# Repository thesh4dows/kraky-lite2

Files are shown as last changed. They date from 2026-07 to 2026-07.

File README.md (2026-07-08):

# kraky-lite2

Kraky-lite2 is the second version of the project kraky-lite.
The project Kraky-lite was inspired by Kraky, another project that i'm developing, and the focus
is to create a cheaper and DIY alternative for the flipper zero.

In this version the PCB is divided in 2 layers, one for power delivery and one for signal.

You can use it connected to a battery via the 18650 slot in the back or connected via usb-c.

I would soggest putting first all the smd commponents on the top layer, then the smd components on the bottom layer, and last the tht components.

I started this journey because i want to create a better version of my project kraky-lite, and i'm doing it by first using smd components instead of the 
tht modules so i can do some expirience soldering very small parts and stopping using pre made modules but recreating them myself.

---

# Main Components
| Function | Component |
|---|---|
| Logic board | **ESP32-S3 N16R8** |
| wifi | **nrf24l01** |
| Sub-GHz | **CC1101** |
| Battery charger | **CN3163** |
| Battery | **INR18650** |
| microSD Slot | **MSD4A** |
| Buttons | 1 tactile buttons and a rotary encoder |
| Display | TFT Display |
| COM converter | **CH343P** |

---

# WIRING DIAGRAM

# ESP32



 # POWER DELIVERY SYSTEM
 


# WIFI



# SUB-GHZ



# MICROSD SLOT



# DISPLAY



---

# PCB



---

# 3D render



---

# Responsible Use
Kraky-lite2 is built to make it easier for anyone to explore and understand how multifunction electronic devices work in everyday life. It’s not intended for bypassing security systems or breaking any laws.

All features are implemented with an educational and experimental focus.

---

# Tools Used

- KiCad 10
- Fusion360
- PlatformIO
---
## Contributing

All the Kraky's tools are an **open and educational project**.  
Feedback, suggestions, and improvements are always welcome.

---

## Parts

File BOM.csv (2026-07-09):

name | value | link | description | cost | quantity
resistors
R1 | 56k | https://it.aliexpress.com/item/1005010070793079.html?curPageLogUid=H7QIyXNC0fT4 | 805 | 4.37 | 1
R2 | 5.1k | https://it.aliexpress.com/item/1005010070793079.html?curPageLogUid=H7QIyXNC0fT4 | 805 | 4.37 | 2
R3 | 330 | https://it.aliexpress.com/item/1005010070793079.html?curPageLogUid=H7QIyXNC0fT4 | 805 | 4.37 | 1
R4 | 3.6k | https://it.aliexpress.com/item/1005010070793079.html?curPageLogUid=H7QIyXNC0fT4 | 805 | 4.37 | 1
R5 | 100 | https://it.aliexpress.com/item/1005010070793079.html?curPageLogUid=H7QIyXNC0fT4 | 805 | 4.33 | 1
R6 | R2 | R2 | R2 | R2 | R2
R7 | 1M | https://it.aliexpress.com/item/1005010070793079.html?curPageLogUid=H7QIyXNC0fT4 | 805 | 4.38 | 1
R8 | 22k | https://it.aliexpress.com/item/1005010070793079.html?curPageLogUid=H7QIyXNC0fT4 | 805 | 4.37 | 1
R9 | 10k | https://it.aliexpress.com/item/1005010070793079.html?curPageLogUid=H7QIyXNC0fT4 | 805 | 4.41 | 3
R10 | R9 | R9 | R9 | R9 | R9
R11 | R9 | R9 | R9 | R9 | R9
capacitors
C1 | 27 pF | https://it.aliexpress.com/item/1005005929029743.html?curPageLogUid=6vnH26Bvr1Cc | 805 | 4.48 | 2
C2 | C1 | C1 | C1 | C1 | C1
C3 | 100 nF | https://it.aliexpress.com/item/1005005929029743.html?curPageLogUid=6vnH26Bvr1Cc | 805 | 4.30 | 10
C4 | C3 | C3 | C3 | C3 | C3
C5 | C3 | C3 | C3 | C3 | C3
C6 | C3 | C3 | C3 | C3 | C3
C7 | C3 | C3 | C3 | C3 | C3
C8 | C3 | C3 | C3 | C3 | C3
C9 | C3 | C3 | C3 | C3 | C3
C10 | 220 pF | https://it.aliexpress.com/item/1005005929029743.html?curPageLogUid=6vnH26Bvr1Cc | 805 | 4.48 | 2
C11 | 3.9 pF | https://it.aliexpress.com/item/1005005929029743.html?curPageLogUid=6vnH26Bvr1Cc | 805 | 4.48 | 2
C12 | 8.2 pF | https://it.aliexpress.com/item/1005005929029743.html?curPageLogUid=6vnH26Bvr1Cc | 805 | 4.48 | 1
C13 | C10 | C10 | C10 | C10 | C10
C14 | C11 | C11 | C11 | C11 | C11
C15 | 5.6 pF | https://it.aliexpress.com/item/1005005929029743.html?curPageLogUid=6vnH26Bvr1Cc | 805 | 4.48 | 1
C16 | 0.1 uF | https://it.aliexpress.com/item/1005005929029743.html?curPageLogUid=6vnH26Bvr1Cc | 805 | 4.30 | 2
C17 | C16 | C16 | C16 | C16 | C16
C18 | 22 uF | https://it.aliexpress.com/item/1005005929029743.html?curPageLogUid=6vnH26Bvr1Cc | 805 | 4.71 | 1
C19 | 4.7 uF | https://it.aliexpress.com/item/1005005929029743.html?curPageLogUid=6vnH26Bvr1Cc | 805 | 4.71 | 1
C20 | C3 | C3 | C3 | C3 | C3
C21 | 22 pF | https://it.aliexpress.com/item/1005005929029743.html?curPageLogUid=6vnH26Bvr1Cc | 805 | 4.48 | 2
C22 | C21 | C21 | C21 | C21 | C21
C23 | 10 nF | https://it.aliexpress.com/item/1005005929029743.html?curPageLogUid=6vnH26Bvr1Cc | 805 | 4.45 | 2
C24 | 1 nF | https://it.aliexpress.com/item/1005005929029743.html?curPageLogUid=6vnH26Bvr1Cc | 805 | 4.45 | 2
C25 | 2.2 nF | https://it.aliexpress.com/item/1005005929029743.html?curPageLogUid=6vnH26Bvr1Cc | 805 | 4.45 | 1
C26 | 4.7 pF | https://it.aliexpress.com/item/1005005929029743.html?curPageLogUid=6vnH26Bvr1Cc | 805 | 4.45 | 1
C27 | 1.5 pF | https://it.aliexpress.com/item/1005005929029743.html?curPageLogUid=6vnH26Bvr1Cc | 805 | 4.45 | 1
C28 | 1 pF | https://it.aliexpress.com/item/1005005929029743.html?curPageLogUid=6vnH26Bvr1Cc | 805 | 4.45 | 1
C29 | C3 | C3 | C3 | C3 | C3
C30 | C3 | C3 | C3 | C3 | C3
C31 | 10 uF | https://it.aliexpress.com/item/1005005929029743.html?curPageLogUid=6vnH26Bvr1Cc | 805 | 4.56 | 2
C32 | C31 | C31 | C31 | C31 | C31
C33 | C23 | C23 | C23 | C23 | C23
C34 | C24 | C24 | C24 | C24 | C24
C35 | 220 uF | https://it.aliexpress.com/item/1005007283100591.html?curPageLogUid=XSGI4u0Avtv0 | 1210 | 6.09 | 2
C36 | C35 | C35 | C35 | C35 | C35
inductors
L1 | 27 nH | https://it.aliexpress.com/item/1005003062755166.html?curPageLogUid=HGVAlLHM7vi2 | 805 | 4.66 | 3
L2 | L1 | L1 | L1 | L1 | L1
L3 | 22 nH | https://it.aliexpress.com/item/1005003062755166.html?curPageLogUid=HGVAlLHM7vi2 | 805 | 4.66 | 1
L4 | L1 | L1 | L1 | L1 | L1
L5 | 2.7 nH | https://it.aliexpress.com/item/1005003062755166.html?curPageLogUid=HGVAlLHM7vi2 | 805 | 4.69 | 1
L6 | 8.2 nH | https://it.aliexpress.com/item/1005003062755166.html?curPageLogUid=HGVAlLHM7vi2 | 805 | 4.66 | 1
L7 | 3.9 nH | https://it.aliexpress.com/item/1005003062755166.html?curPageLogUid=HGVAlLHM7vi2 | 805 | 4.66 | 1
diodes
D1 | 1N5817 | https://it.aliexpress.com/item/1005006884142108.html?curPageLogUid=pNE6jaPw82sV |  | 5.99 | 3
D2 | LED | https://it.aliexpress.com/item/32868897187.html?curPageLogUid=WrrkifD2CvJr | 1206 | 4.63 | 1
D3 | LED | https://it.aliexpress.com/item/32868897187.html?curPageLogUid=WrrkifD2CvJr | 1206 | 4.63 | 1
D4 | LED | https://it.aliexpress.com/item/32868897187.html?curPageLogUid=WrrkifD2CvJr | 1206 | 4.63 | 1
D5 | D1 | D1 | D1 | D1 | D1
D6 | D1 | D1 | D1 | D1 | D1
Crystals
Y1 | 26 MHz | https://it.aliexpress.com/item/1005004711354176.html?curPageLogUid=sEWfQk2pigRD | 5032 | 5.79 | 1
Y2 | 16MHz | https://it.aliexpress.com/item/1005007210644647.html?curPageLogUid=bcvfZR4XvBPS | 5032 | 7.15 | 1
switches
SW1 | rotary encoder | https://it.aliexpress.com/item/1005005983134515.html?curPageLogUid=CHuD8wUJHaKP |  | 6.19 | 1
SW2 | RST | https://it.aliexpress.com/item/1005008404608815.html?curPageLogUid=beYw408Avuco | 3x6 | 5.36 | 2
SW3 | BOOT | SW2 | SW2 | SW2 | SW2
SW4 | BACK | https://it.aliexpress.com/item/1005006870284823.html?curPageLogUid=iBAjoDabdN8o | 6x6 | 6.01 | 1
SW5 | ON/OFF | https://it.aliexpress.com/item/1005004328667818.html?scm_id=1007.40050.354490.0&scm-url=1007.40050.354490.0 | tht | 5.68 | 1
connectors
J1 | usb-c port | https://it.aliexpress.com/item/1005010643898257.html?curPageLogUid=aFt3XDvcOZhM |  | 5.36 | 1
J2 | display | https://it.aliexpress.com/item/1005007561214068.html?curPageLogUid=LR6KpiatdhUQ |  | 9.69 | 1
J3 | battery holder | https://it.aliexpress.com/item/4000692031094.html?curPageLogUid=Iut4p1SU8Gy9 |  | 5.04 | 1
J4 | 142-0701-501 | https://it.aliexpress.com/item/1005009514982478.html?curPageLogUid=lCuaA8hYuMzd | sma antenna | 5.62 | 2
J5 | MSD-4-A | https://it.aliexpress.com/item/1005006273533788.html?scm_id=1007.40050.354490.0&scm-url=1007.40050.354490.0 | microsd-slot | 5.25 | 1
J6 | J4 | J4 | J4 | J4 | J4
ics
U1 | AMS1117-3.3 | https://it.aliexpress.com/item/1005007027620474.html?curPageLogUid=eo6dvrBMm3cE |  | 4.93 | 1
U2 | AP2112K-3.3TRG1 | https://it.aliexpress.com/item/1005005807114594.html?curPageLogUid=mb5UjEPLbEDJ |  | 5.06 | 1
U3 | CH343P | https://it.aliexpress.com/item/1005009691777003.html?curPageLogUid=lfFt8St0bZKK |  | 7.54 | 1
U4 | CN3063-SOIC8 | https://it.aliexpress.com/item/1005006908180461.html?curPageLogUid=8cHjriHsLvvB |  | 5.59 | 1
U5 | NRF24L01 | https://it.aliexpress.com/item/1005008669394507.html?curPageLogUid=WSLfC61CjqIJ |  | 6.25 | 1
U6 | CC1101 | https://it.aliexpress.com/item/1005007128993296.html?curPageLogUid=uCi7b2Ehsp0B |  | 4.89 | 1
U7 | ESP32-S3-WROOM-1 | https://it.aliexpress.com/item/1005006214506085.html |  | 7.98 | 1
others
battery |  | https://it.aliexpress.com/item/4000809394148.html?curPageLogUid=ac2SQacPb3IK |  | 4.39 | 1
antennas |  | https://it.aliexpress.com/item/1005009456185238.html?curPageLogUid=LOvsTqpqLuYX |  | 6.10 | 2
tools
solder paste |  | https://it.aliexpress.com/item/1005008590694612.html?curPageLogUid=S2Oe7UAJmCP7 |  | 6.32 | 1
solder spool |  | https://it.aliexpress.com/item/1005012037824511.html?curPageLogUid=fqKpRQII2cfI |  | 13.59 | 1
PCB
pcb |  | jlcpcb |  | 30.21 | 1
stencil |  | pcb |  | pcb | 1

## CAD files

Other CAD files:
3D renders/kraky-lite2.3mf

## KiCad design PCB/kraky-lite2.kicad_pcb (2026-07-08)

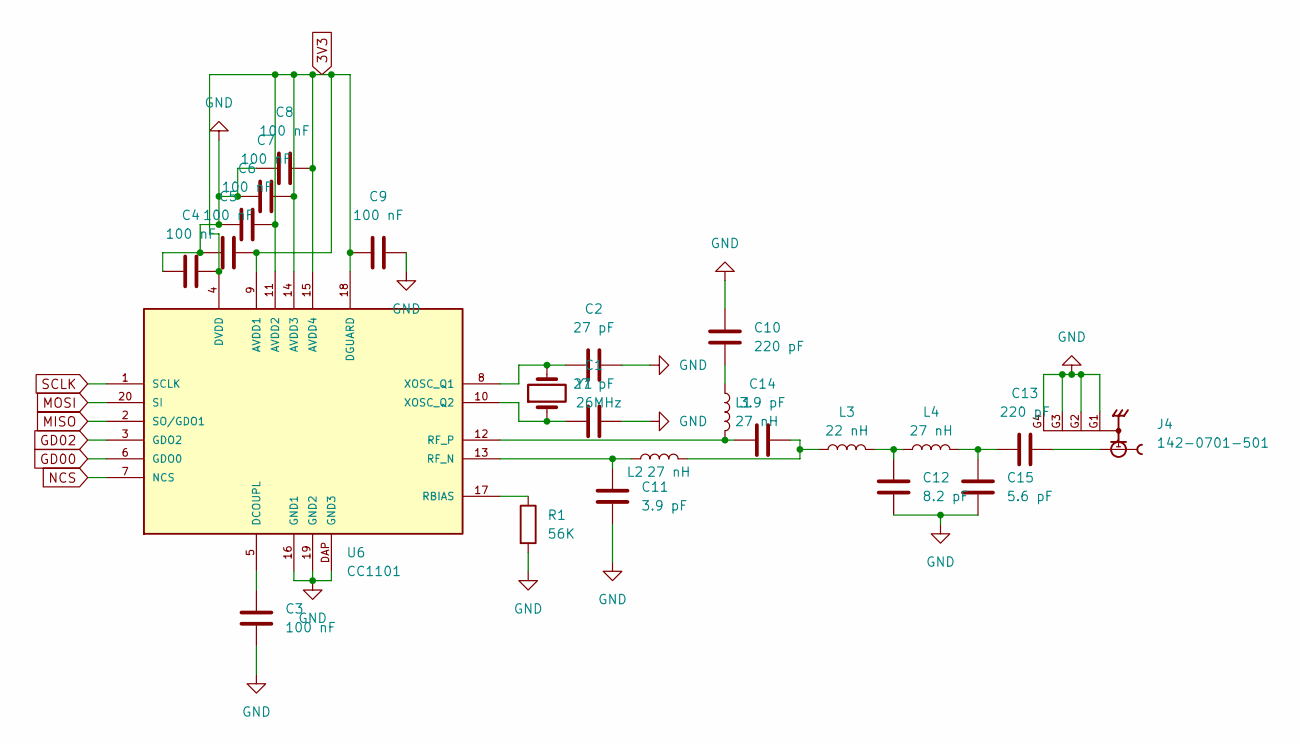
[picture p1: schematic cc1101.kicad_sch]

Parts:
C1, C2: 27 pF; C_0805_2012Metric
C3, C4, C5, C6, C7, C8, C9: 100 nF; C_0805_2012Metric
C10, C13: 220 pF; C_0805_2012Metric
C11, C14: 3.9 pF; C_0805_2012Metric
C12: 8.2 pF; C_0805_2012Metric
C15: 5.6 pF; C_0805_2012Metric
J4: 142-0701-501; SMA_Molex_73251-1153_EdgeMount_Horizontal; PARTREV 7c
L1, L2, L4: 27 nH; L_0805_2012Metric
L3: 22 nH; L_0805_2012Metric
R1: 56K; R_0805_2012Metric
U6: CC1101; QLP20
Y1: 26MHz; Crystal_SMD_5032-2Pin_5.0x3.2mm_HandSoldering

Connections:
3V3: C4.2, C5.2, C6.2, C7.2, C8.2, C9.2, U6.4 (DVDD), U6.9 (AVDD1), U6.11 (AVDD2), U6.14 (AVDD3), U6.15 (AVDD4), U6.18 (DGUARD); also elsewhere on the board
GD00: U6.6 (GDO0); also elsewhere on the board
GD02: U6.3 (GDO2); also elsewhere on the board
GND: C1.2, C2.2, C3.2, C4.1, C5.1, C6.1, C7.1, C8.1, C9.1, C10.2, C11.1, C12.2, C15.2, J4.G1, J4.G2, J4.G3, J4.G4, R1.2, U6.16 (GND1), U6.19 (GND2), U6.DAP (GND3); also elsewhere on the board
MISO: U6.2 (SO/GDO1); also elsewhere on the board
MOSI: U6.20 (SI); also elsewhere on the board
NCS: U6.7 (NCS); also elsewhere on the board
unnamed: C10.1, L1.1
unnamed: C12.1, L3.2, L4.1
unnamed: C13.1, C15.1, L4.2
unnamed: C13.2, J4.1
unnamed: C14.2, L2.2, L3.1
unnamed: C3.1, U6.5 (DCOUPL)
unnamed: R1.1, U6.17 (RBIAS)
unnamed: C11.2, L2.1, U6.13 (RF_N)
unnamed: C14.1, L1.2, U6.12 (RF_P)
unnamed: C2.1, U6.8 (XOSC_Q1), Y1.2
unnamed: C1.1, U6.10 (XOSC_Q2), Y1.1
SCLK: U6.1 (SCLK); also elsewhere on the board

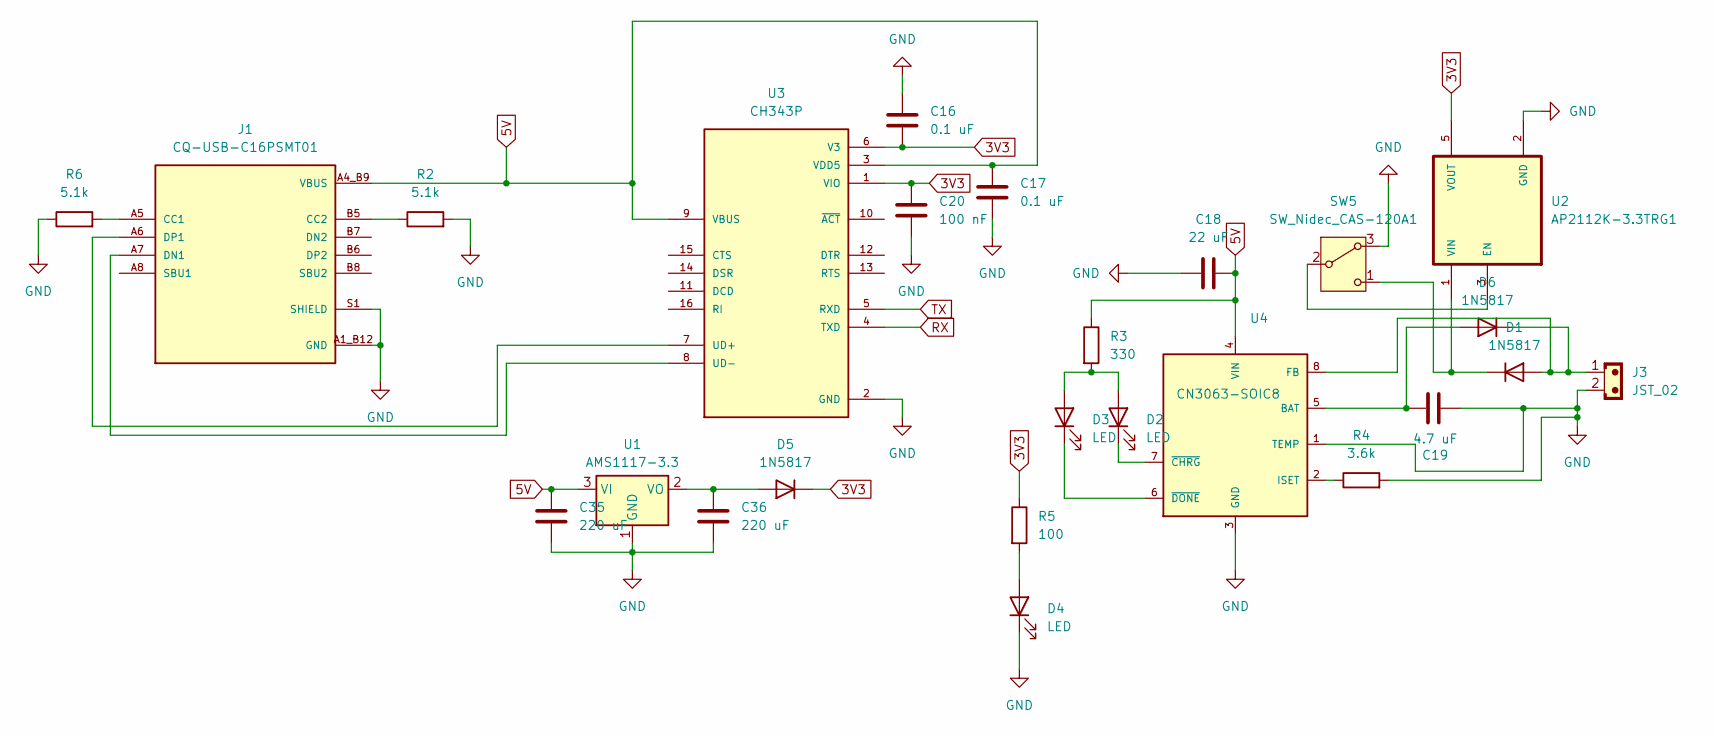
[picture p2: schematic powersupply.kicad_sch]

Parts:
C16, C17: 0.1 uF; C_0805_2012Metric
C18: 22 uF; C_0805_2012Metric
C19: 4.7 uF; C_0805_2012Metric
C20: 100 nF; C_0805_2012Metric
C35, C36: 220 uF; C_1210_3225Metric
D1, D5, D6: 1N5817; D_SMA_Handsoldering
D2, D3, D4: LED; LED_1206_3216Metric
J1: CQ-USB-C16PSMT01; SHENZHEN-CHUANGQIN-TECHNOLOGY_CQ-USB-C16PSMT01; PARTREV A
J3: JST_02; BatteryHolder_Keystone_1042_1x18650
R2, R6: 5.1k; R_0805_2012Metric
R3: 330; R_0805_2012Metric
R4: 3.6k; R_0805_2012Metric
R5: 100; R_0805_2012Metric
SW5: SW_Nidec_CAS-120A1; SW_Slide_SPDT_Angled_CK_OS102011MA1Q
U1: AMS1117-3.3; SOT-223-3_TabPin2
U2: AP2112K-3.3TRG1; SOT95P285X140-5N; PARTREV 2-2
U3: CH343P; QFN50P300X300X80-17N; PARTREV 1E
U4: CN3063-SOIC8; SOIC8-1.27-5X4MM; MPN CN3063

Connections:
3V3: C16.2, C20.1, D5.1 (K), R5.1, U2.5 (VOUT), U3.1 (VIO), U3.6 (V3); also elsewhere on the board
5V: C17.1, C18.2, C35.1, J1.A4_B9 (VBUS), J1.B4_A9 (VBUS), R3.1, U1.3 (VI), U3.3 (VDD5), U3.9 (VBUS), U4.4 (VIN)
GND: C16.1, C17.2, C18.1, C19.2, C20.2, C35.2, C36.2, D4.1 (K), J1.A1_B12 (GND), J1.B1_A12 (GND), J1.S1 (SHIELD), J1.S2 (SHIELD), J1.S3 (SHIELD), J1.S4 (SHIELD), J3.2, R2.2, R4.2, R6.1, SW5.3 (A), U1.1 (GND), U2.2 (GND), U3.2 (GND), U3.17 (GND), U4.1 (TEMP), U4.3 (GND); also elsewhere on the board
unnamed: D1.2 (A), D6.1 (K), J3.1, U4.8 (FB)
unnamed: D1.1 (K), SW5.1 (C), U2.1 (VIN)
unnamed: D2.2 (A), D3.2 (A), R3.2
unnamed: D2.1 (K), U4.7 (~CHRG)
unnamed: D3.1 (K), U4.6 (~DONE)
unnamed: D4.2 (A), R5.2
unnamed: C36.1, D5.2 (A), U1.2 (VO)
unnamed: C19.1, D6.2 (A), U4.5 (BAT)
unnamed: J1.A5 (CC1), R6.2
unnamed: J1.B5 (CC2), R2.1
unnamed: J1.A7 (DN1), U3.8 (UD-)
unnamed: J1.A6 (DP1), U3.7 (UD+)
unnamed: SW5.2 (B), U2.3 (EN)
unnamed: R4.1, U4.2 (ISET)
RX: U3.4 (TXD); also elsewhere on the board
TX: U3.5 (RXD); also elsewhere on the board

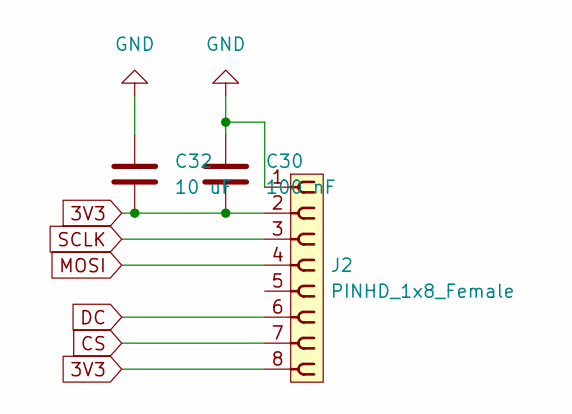
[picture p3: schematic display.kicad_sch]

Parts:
C30: 100 nF; C_0805_2012Metric
C32: 10 uF; C_0805_2012Metric
J2: PINHD_1x8_Female; PinSocket_1x08_P2.54mm_Vertical

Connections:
3V3: C30.2, C32.2, J2.2, J2.8; also elsewhere on the board
CS: J2.7; also elsewhere on the board
DC: J2.6; also elsewhere on the board
GND: C30.1, C32.1, J2.1; also elsewhere on the board
MOSI: J2.4; also elsewhere on the board
SCLK: J2.3; also elsewhere on the board

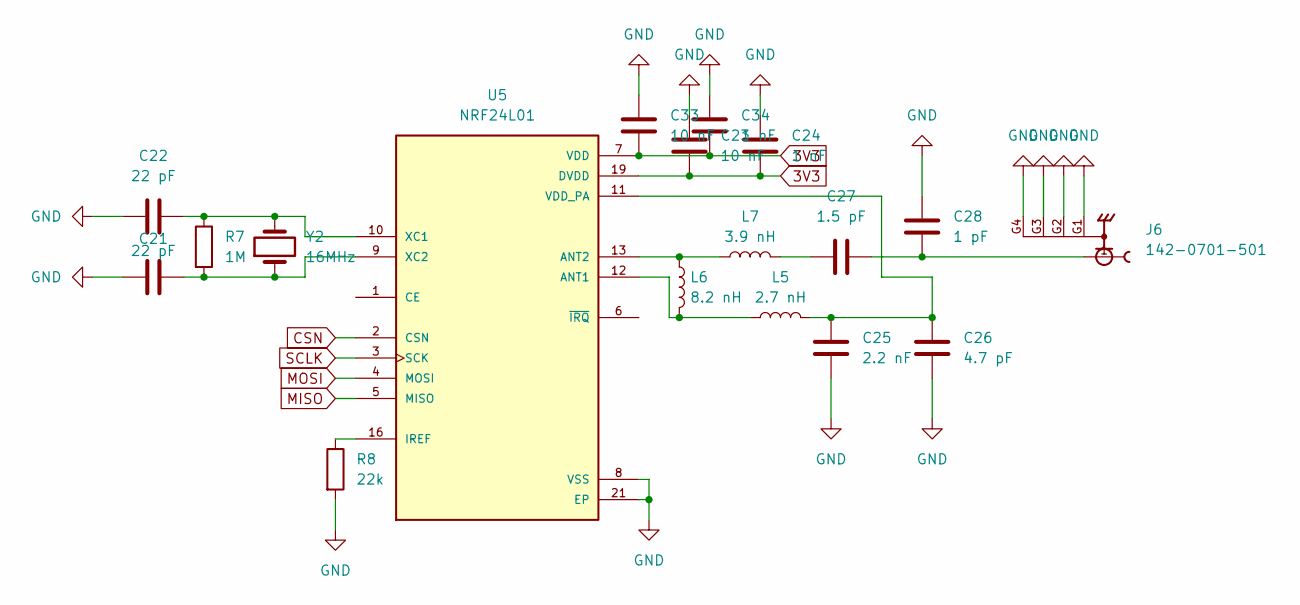
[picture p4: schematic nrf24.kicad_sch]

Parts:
C21, C22: 22 pF; C_0805_2012Metric
C23, C33: 10 nF; C_0805_2012Metric
C24, C34: 1 nF; C_0805_2012Metric
C25: 2.2 nF; C_0805_2012Metric
C26: 4.7 pF; C_0805_2012Metric
C27: 1.5 pF; C_0805_2012Metric
C28: 1 pF; C_0805_2012Metric
J6: 142-0701-501; SMA_Molex_73251-1153_EdgeMount_Horizontal; PARTREV 7c
L5: 2.7 nH; L_0805_2012Metric
L6: 8.2 nH; L_0805_2012Metric
L7: 3.9 nH; L_0805_2012Metric
R7: 1M; R_0805_2012Metric
R8: 22k; R_0805_2012Metric
U5: NRF24L01; QFN50P400X400X95-21N; PARTREV 2.0
Y2: 16MHz; Crystal_SMD_5032-2Pin_5.0x3.2mm_HandSoldering

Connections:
3V3: C23.2, C24.1, C33.2, C34.1, U5.7 (VDD), U5.15 (VDD), U5.18 (VDD), U5.19 (DVDD); also elsewhere on the board
CSN: U5.2 (CSN); also elsewhere on the board
GND: C21.1, C22.1, C23.1, C24.2, C25.2, C26.2, C28.1, C33.1, C34.2, J6.G1, J6.G2, J6.G3, J6.G4, R8.2, U5.8 (VSS), U5.14 (VSS), U5.17 (VSS), U5.20 (VSS), U5.21 (EP); also elsewhere on the board
MISO: U5.5 (MISO); also elsewhere on the board
MOSI: U5.4 (MOSI); also elsewhere on the board
unnamed: C27.1, L7.2
unnamed: C27.2, C28.2, J6.1
unnamed: L5.1, L6.2, U5.12 (ANT1)
unnamed: L6.1, L7.1, U5.13 (ANT2)
unnamed: R8.1, U5.16 (IREF)
unnamed: C25.1, C26.1, L5.2, U5.11 (VDD_PA)
unnamed: C22.2, R7.1, U5.10 (XC1), Y2.2
unnamed: C21.2, R7.2, U5.9 (XC2), Y2.1
SCLK: U5.3 (SCK); also elsewhere on the board

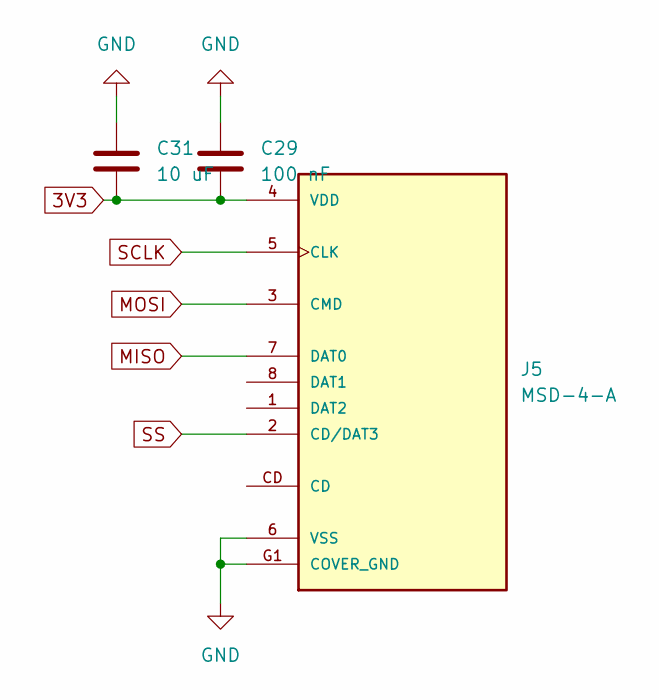
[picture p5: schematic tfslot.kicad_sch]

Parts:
C29: 100 nF; C_0805_2012Metric
C31: 10 uF; C_0805_2012Metric
J5: MSD-4-A; CUI_MSD-4-A; PARTREV 1.0

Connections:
3V3: C29.2, C31.2, J5.4 (VDD); also elsewhere on the board
GND: C29.1, C31.1, J5.6 (VSS), J5.G1 (COVER_GND), J5.G2 (COVER_GND), J5.G3 (COVER_GND), J5.G4 (COVER_GND); also elsewhere on the board
MISO: J5.7 (DAT0); also elsewhere on the board
MOSI: J5.3 (CMD); also elsewhere on the board
SCLK: J5.5 (CLK); also elsewhere on the board
SS: J5.2 (CD/DAT3); also elsewhere on the board

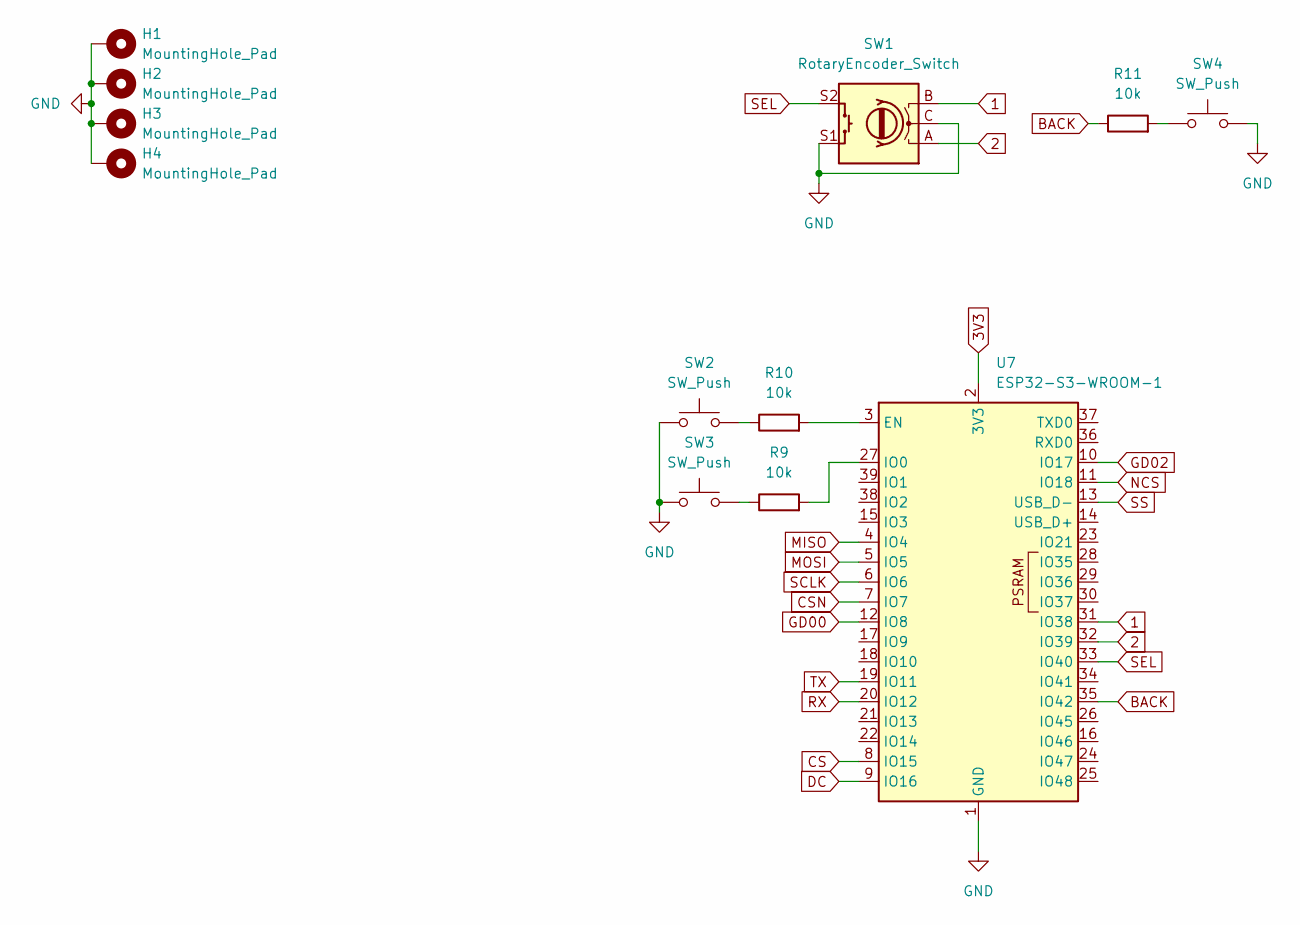
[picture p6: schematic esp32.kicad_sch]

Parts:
H1, H2, H3, H4: MountingHole_Pad; MountingHole_2.2mm_M2_DIN965_Pad
R9, R10, R11: 10k; R_0805_2012Metric
SW1: RotaryEncoder_Switch; RotaryEncoder_Alps_EC11E-Switch_Vertical_H20mm
SW2, SW3: SW_Push; SW_SPST_EVQPE1
SW4: SW_Push; SW_SPST_PTS645Sx43SMTR92
U7: ESP32-S3-WROOM-1

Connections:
1: SW1.B, U7.31 (IO38)
2: SW1.A, U7.32 (IO39)
3V3: U7.2 (3V3); also elsewhere on the board
BACK: R11.1, U7.35 (IO42)
CS: U7.8 (IO15); also elsewhere on the board
CSN: U7.7 (IO7); also elsewhere on the board
DC: U7.9 (IO16); also elsewhere on the board
GD00: U7.12 (IO8); also elsewhere on the board
GD02: U7.10 (IO17); also elsewhere on the board
GND: H1.1 (1_1), H2.1 (1_1), H3.1 (1_1), H4.1 (1_1), SW1.C, SW1.S1, SW2.1, SW3.1, SW4.2, U7.1 (GND), U7.40 (GND), U7.41 (GND); also elsewhere on the board
MISO: U7.4 (IO4); also elsewhere on the board
MOSI: U7.5 (IO5); also elsewhere on the board
NCS: U7.11 (IO18); also elsewhere on the board
unnamed: R9.1, SW3.2
unnamed: R10.1, SW2.2
unnamed: R11.2, SW4.1
unnamed: R10.2, U7.3 (EN)
unnamed: R9.2, U7.27 (IO0)
RX: U7.20 (IO12); also elsewhere on the board
SCLK: U7.6 (IO6); also elsewhere on the board
SEL: SW1.S2, U7.33 (IO40)
SS: U7.13 (USB_D-); also elsewhere on the board
TX: U7.19 (IO11); also elsewhere on the board

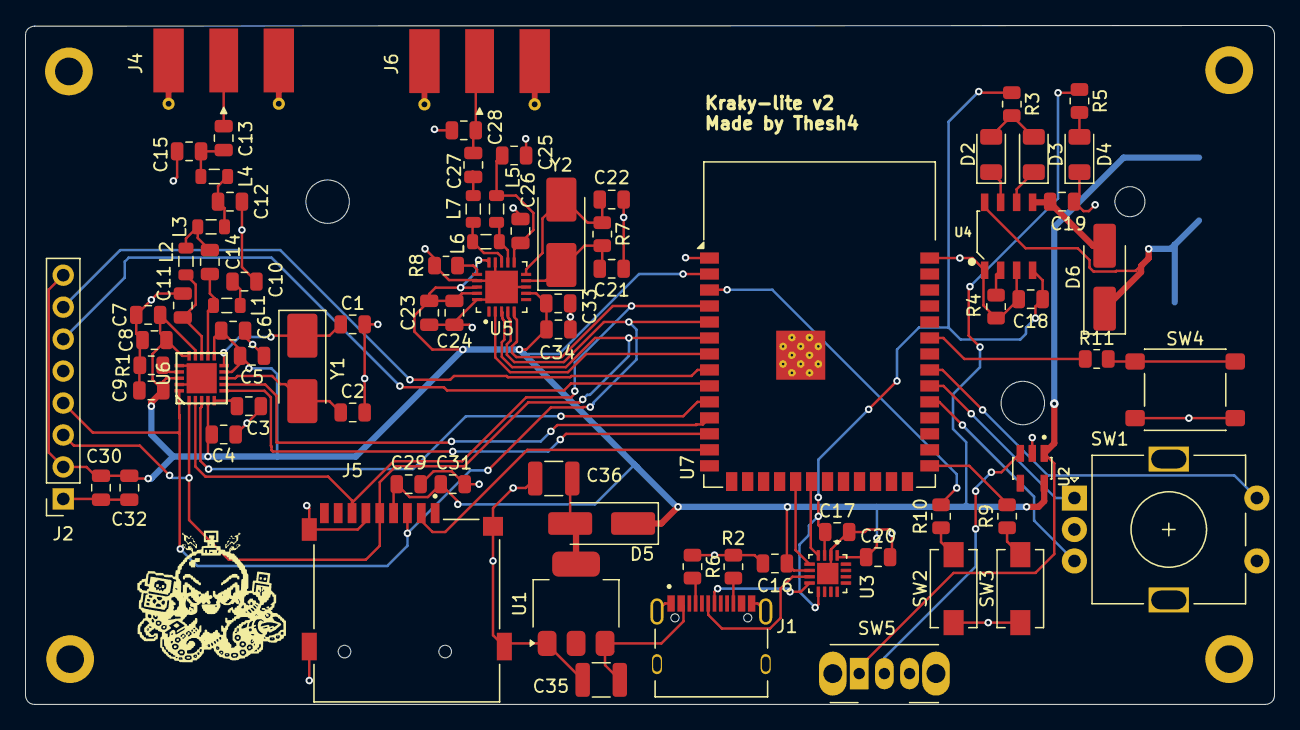
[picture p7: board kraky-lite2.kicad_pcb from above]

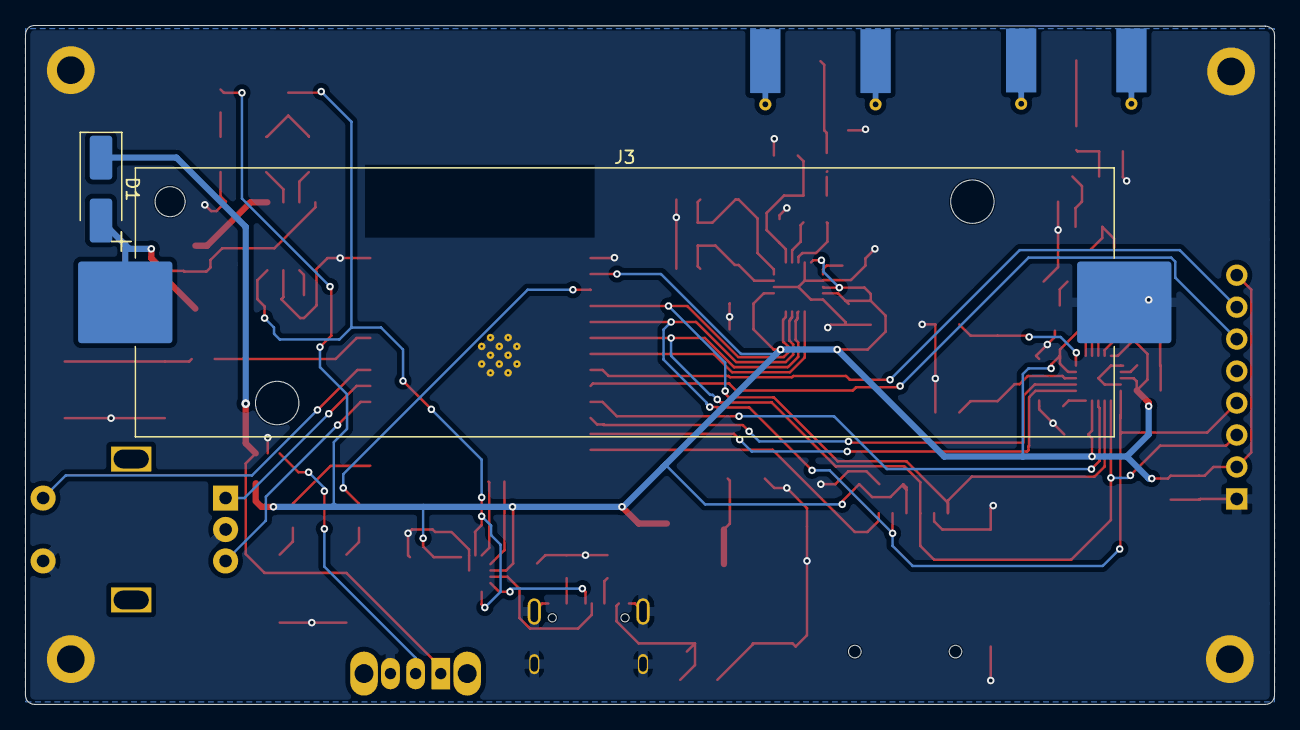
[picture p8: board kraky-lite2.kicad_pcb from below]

Board: 2 copper layers, 99.2 x 53.9 mm, 84 parts (2 on the bottom side), 57 nets.

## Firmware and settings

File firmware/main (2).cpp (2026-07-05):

/*
 * KRAKY2
 */

#include <Arduino.h>
#include <WiFi.h>
#include <Wire.h>
#include <SPI.h>

// ================= PIN =================

// Pulsanti
#define BTN_UP     41
#define BTN_DOWN   38
#define BTN_OK     40
#define BTN_BACK   39


// SPI (VSPI)
#define SPI_SCK    21
#define SPI_MISO   17
#define SPI_MOSI   18

// PN532 E
#include <Adafruit_PN532.h>
#define NFC_SS     1
#define NFC_ANTSEL 5
Adafruit_PN532 nfc(NFC_SS);

// LoRa D
#include <RadioLib.h>
#define LORA_CSN   3 //attivo se low
#define LORA_DIO0  2
CC1101 cc1101 = new Module(LORA_CSN, LORA_DIO0, RADIOLIB_NC, RADIOLIB_NC);

//IR
#include <IRremote.hpp>
#define IR_LED     42
#define IR_REC     45

//DISPLAY A ST7789
#include <Adafruit_GFX.h>
#include <Adafruit_ST7789.h>
#define DS_CS      46
#define DS_DC      47
Adafruit_ST7789 tft = Adafruit_ST7789(DS_CS, DS_DC, -1);

//WIFI B
#include <RF24.h>
#define WIFI_CSN   48 //attivo se low 
#define WIFI_CE    4
#include <WiFi.h>
RF24 nrf24(WIFI_CE, WIFI_CSN);
const byte address[6] = "00001";

//RFID F
#include <MFRC522.h>
#define RFID_CSN   6
#define RFID_ANTSEL 7
MFRC522 rfid(RFID_CSN, -1);

//MICRO SD SLOT C
#include <SD.h>
#define MSD_CS     8
//Battery 
#define BAT_PIN 9
//BLUETOOTH
#include <NimBLEDevice.h>
// ================= OGGETTI =================



// ================= MENU =================

struct Item {
  const char* name;
  int id;
  int parent;
};

Item menu[] = {
  {"WiFi",     0, -1},
  {"NFC",      1, -1},
  {"RFID",     2, -1},
  {"Sub-GHz", 3, -1},
  {"Bluetooth", 4, -1},
  {"IR", 5,-1},
  {"Settings", 6, -1},
  // WiFi
  {"Wifi Scan",     7, 0},
  {"Wifi Monitor",  8, 0},

  // NFC
  {"NFC Read",     9, 1},
  {"NFC Write",    10, 1},

  // RFID
  {"RFID Dump",     11, 2},
  {"RFID Clone",    12, 2},

  // subghz
  {"Sub-GHz Scan", 13, 3},
  {"Sub-GHz Jammer",  14, 3},

  //bluetooth
  {"BLE Scan", 15, 4},
  {"BLE Jammer", 16, 4},

  //IR
  {"IR Scan", 17, 5},
  {"IR Write", 18, 5},

  //settings
  {"Display", 19, 6},
  {"System",  20, 6},
};

int menuSize = sizeof(menu) / sizeof(menu[0]);

// ---------------- NAV STACK ----------------
int parentStack[10];
int selectedStack[10];
int level = 0;
int currentParent = -1;
int selected = 0;
int visibleItems[20];
int visibleCount = 0;
// ---------------- DRAW ----------------
void drawMenu() {
  tft.fillScreen(ST77XX_BLACK);
  tft.setTextSize(1);
  visibleCount = 0;
  int y = 20;

  for (int i = 0; i < menuSize; i++) {

    if (menu[i].parent == currentParent) {
      visibleItems[visibleCount] = i;
      visibleCount++;
      if (i == selected) {
        tft.setTextColor(ST77XX_BLACK, ST77XX_WHITE);
      } else {
        tft.setTextColor(ST77XX_WHITE);
      }

      tft.setCursor(10, y);
      tft.print(menu[i].name);
      y += 15;
    }
  }
}

// ---------------- FIND NEXT ----------------
int findNext(int start, int dir) {
  int i = start;

  while (true) {
    i += dir;
    if (i < 0) i = visibleCount - 1;
    if (i >= visibleCount) i = 0;

    return i;
  }
}


// ================= SETUP =================

void setup(){
  SPI.begin();
  //display
  tft.init(172, 320);
  tft.setRotation(1);
  tft.fillScreen(ST77XX_BLACK);
  //LoRa
  int state = cc1101.begin(868.0); // o 915.0
  //IR
  IrSender.begin(IR_LED); 
  IrReceiver.begin(IR_REC, ENABLE_LED_FEEDBACK);
  //WIFI
    //modalità trasmissione
  nrf24.begin();
  nrf24.openWritingPipe(address);
  nrf24.setPALevel(RF24_PA_LOW);
  nrf24.stopListening();
    //modalità ricezione
  nrf24.begin();
  nrf24.openReadingPipe(0, address);
  nrf24.setPALevel(RF24_PA_LOW);
  nrf24.startListening();
  //RFID
  rfid.PCD_Init();
  rfid.PCD_DumpVersionToSerial();
  //NFC
  nfc.begin();
  nfc.SAMConfig(); //modalità ascolto
  //Menù
  pinMode(BTN_UP, INPUT_PULLUP);
  pinMode(BTN_DOWN, INPUT_PULLUP);
  pinMode(BTN_OK, INPUT_PULLUP);
  pinMode(BTN_BACK, INPUT_PULLUP);
  drawMenu();
}

// ================= LOOP =================

void loop() {
  //Battery
    int raw = analogRead(BAT_PIN);
    float voltage = ((float)raw / 4095.0) * 3.3 * 2.0;
  //Menù
    // UP
    if (digitalRead(BTN_UP) == LOW) {
      selected = findNext(selected, -1);
      drawMenu();
      delay(150);
    }

    // DOWN
    if (digitalRead(BTN_DOWN) == LOW) {
      selected = findNext(selected, +1);
      drawMenu();
      delay(150);
    }

    // OK → entra nel submenu corretto
    if (digitalRead(BTN_OK) == LOW) {

      parentStack[level] = currentParent;
      selectedStack[level] = selected;
      level++;

      int index = visibleItems[selected];
      currentParent = index;   
      selected = 0;

      drawMenu();
      delay(200);
    }

    // BACK → torna di 1 livello
    if (digitalRead(BTN_BACK) == LOW) {

      if (level > 0) {
        level--;
        if (level > 0) {
        level--;
        currentParent = parentStack[level];
        selected = selectedStack[level];
      } else {
        currentParent = -1;
        selected = 0;
      }
        selected = selectedStack[level];
      }

      drawMenu();
      delay(200);
    }
}

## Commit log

2026-07-05 Rename kraky-lite2.3mf to 3D renders/kraky-lite2.3mf
    [kraky-lite2.3mf]
2026-07-08 Update battery type to INR18650 in README
